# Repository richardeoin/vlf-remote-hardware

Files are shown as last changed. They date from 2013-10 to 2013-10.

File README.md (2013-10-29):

EAGLE CAD Design files for the VLF Remote Unit

## Photo

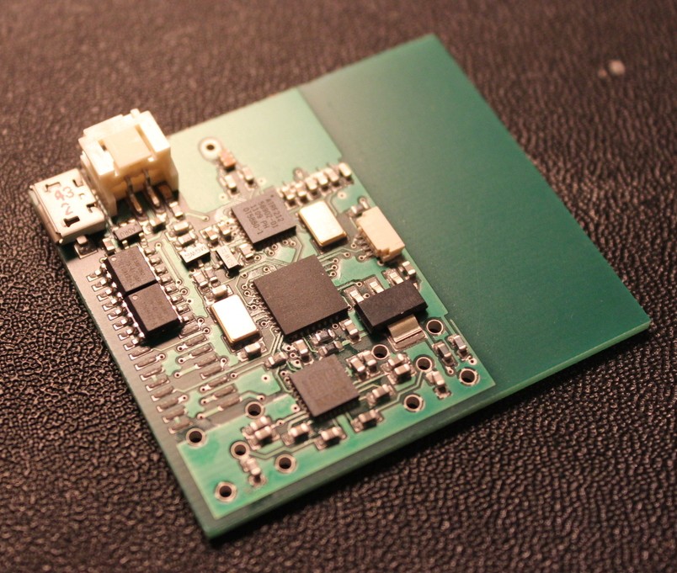
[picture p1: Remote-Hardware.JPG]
Remote Unit


## Design Notes

The board is based around a NXP
[LPC1114](http://www.nxp.com/documents/data_sheet/LPC111X.pdf) ARM
Cortex-M0 microcontroller. A Wolfson
[WM8737 ADC](http://www.wolfsonmicro.com/documents/uploads/data_sheets/en/WM8737.pdf)
is used to record the Very Low Frequency (VLF) signals. Although this
ADC is intended for audio applications it is perfectly adequate for
very low frequency RF signals due to its high gain preamplifiers. It
features low power operation and easily available, probably due to it
being
[used in the Microsoft Kinect](http://techon.nikkeibp.co.jp/english/NEWS_EN/20101205/187927/).

The board has three pads for serial flash and a
[AT86RF212](http://www.atmel.com/images/doc8168.pdf) 868MHz radio. The
range is in the order of 200m in free space, but much lower in practice.

The average current draw is approximately 3mA.

## [License](LICENSE.md)

[MIT](http://opensource.org/licenses/MIT)

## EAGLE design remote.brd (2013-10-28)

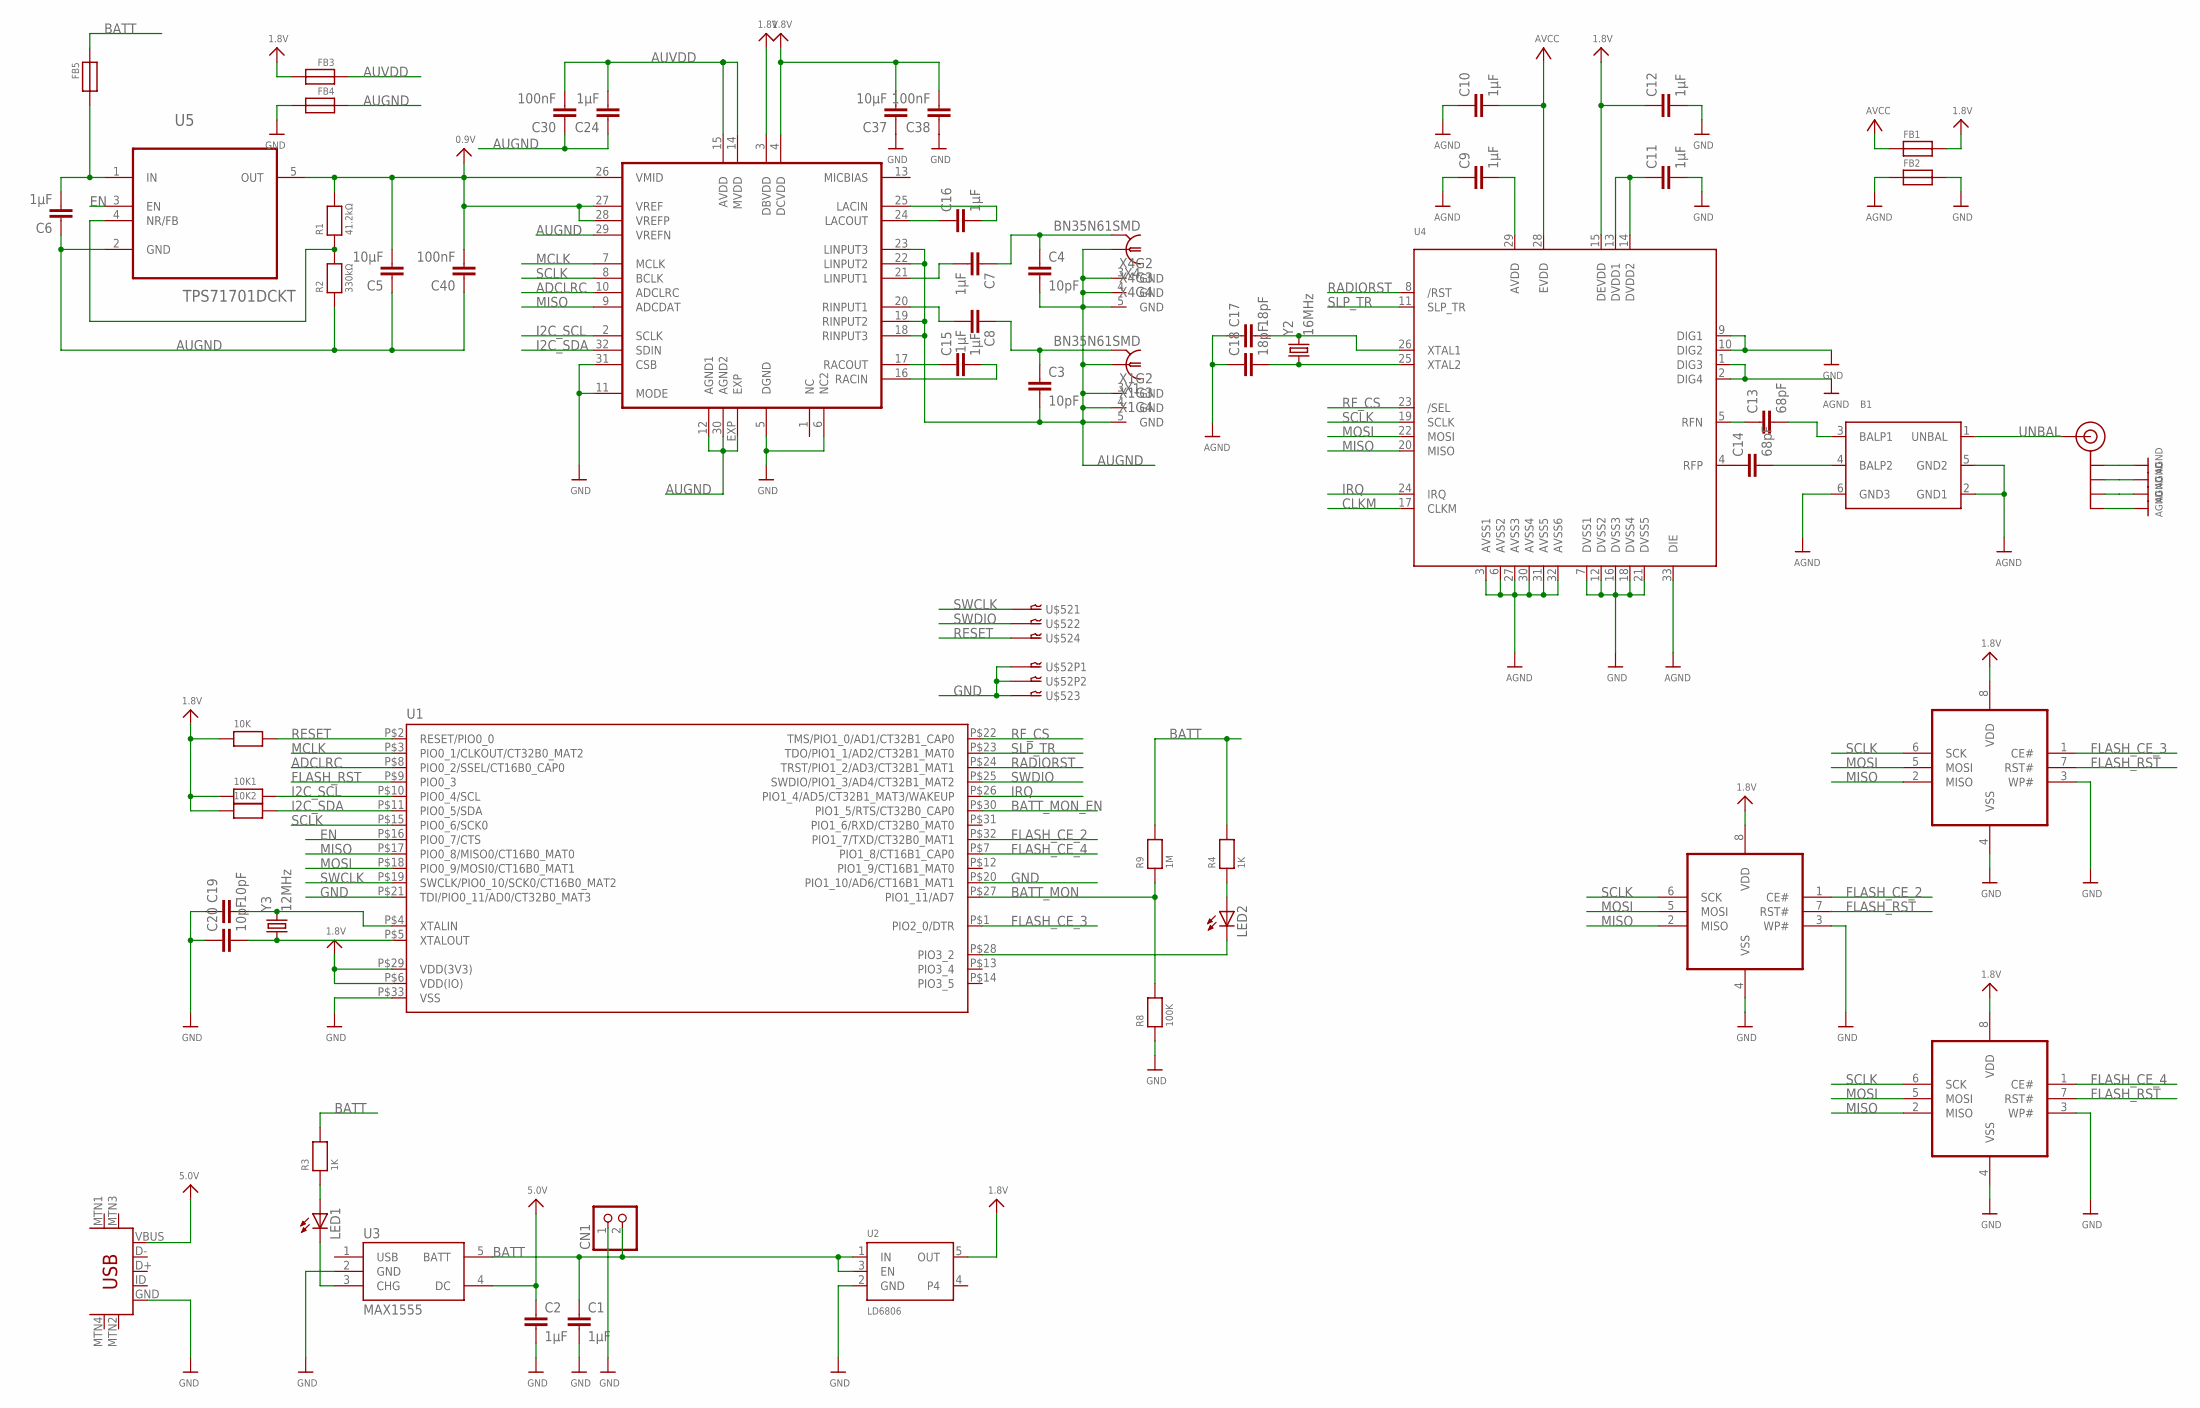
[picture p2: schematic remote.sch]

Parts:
10K, 10K1, 10K2: RESISTOR0603MINI; 0603-MINI
B1: BALUN+LP; BALUN0805
C1, C2, C6, C7, C8, C9, C10, C11, C12, C15, C16, C24: 1µF; C0603K
C3, C4, C19, C20: 10pF; C0603K
C5, C37: 10µF; C0603K
C13, C14: 68pF; C0603K
C17, C18: 18pF; C0603K
C30, C38, C40: 100nF; C0603K
CN1: JST_2PIN; JSTPH2
FB1, FB2, FB3, FB4, FB5: FERRITE; 0603
J$1: SMA_EDGE; SMA-EDGE
LED1, LED2: LEDCHIPLED_0603; CHIPLED_0603
R1: 41.2kΩ; 0603-MINI
R2: 330kΩ; 0603-MINI
R3, R4: 1K; 0603-MINI
R8: 100K; 0603-MINI
R9: 1M; 0603-MINI
U1: LPC1113/4_QFN; HVQFN33-7X7
U2: LD6806; SOT23-5
U3: MAX1555; SOT23-5
U4: AT86RF212; 32QN2
U5: TPS71701DCKT; SOT65P210X110-5N
U$1, U$22, U$26: SST25WF; ZA
U$14: WM8737; DM030FL
U$16: USB-MINIB-5PIN; USB-MINIB
U$52: SM04B-SURS-TF
X1, X4: BN35N61SMD; B35N61_SMD
Y2: 16MHz; CRYSTAL-SMD-5X3
Y3: 12MHz; CRYSTAL-SMD-5X3

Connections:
0.9V: C5.2, C40.2, R1.2, U5.5 (OUT), U$14.26 (VMID), U$14.27 (VREF), U$14.28 (VREFP)
1.8V: 10K.1, 10K1.1, 10K2.1, C12.1, C37.2, C38.2, FB1.2, FB3.2, U1.P$6 (VDD(IO)), U1.P$29 (VDD(3V3)), U2.5 (OUT), U4.15 (DEVDD), U$1.8 (VDD), U$14.3 (DBVDD), U$14.4 (DCVDD), U$22.8 (VDD), U$26.8 (VDD)
5.0V: C2.1, U3.4 (DC), U$16.VBUS
ADCLRC: U1.P$8 (PIO0_2/SSEL/CT16B0_CAP0), U$14.10 (ADCLRC)
AGND: B1.2 (GND1), B1.5 (GND2), B1.6 (GND3), C9.1, C10.1, C17.1, C18.1, FB2.1, J$1.GND@0 (GND), J$1.GND@1 (GND), J$1.GND@2 (GND), J$1.GND@3 (GND), U4.1 (DIG3), U4.2 (DIG4), U4.3 (AVSS1), U4.6 (AVSS2), U4.27 (AVSS3), U4.30 (AVSS4), U4.31 (AVSS5), U4.32 (AVSS6), U4.33 (DIE)
AUBATT: C6.2, FB5.2, U5.1 (IN)
AUGND: C3.2, C4.2, C5.1, C6.1, C24.1, C30.1, C40.1, FB4.1, R2.1, U5.2 (GND), U$14.12 (AGND1), U$14.18 (RINPUT3), U$14.19 (RINPUT2), U$14.22 (LINPUT2), U$14.23 (LINPUT3), U$14.29 (VREFN), U$14.30 (AGND2), U$14.EXP, X1.2 (1), X1.3 (GND), X1.4 (GND), X1.5 (GND), X4.2 (1), X4.3 (GND), X4.4 (GND), X4.5 (GND)
AUVDD: C24.2, C30.2, FB3.1, U$14.14 (MVDD), U$14.15 (AVDD)
AVCC: C10.2, FB1.1, U4.28 (EVDD)
AVDD-IN: C9.2, U4.29 (AVDD)
BALP1: B1.3 (BALP1), C13.2
BALP2: B1.4 (BALP2), C14.2
BATT: C1.1, CN1.2, FB5.1, R3.2, R4.2, R9.2, U2.1 (IN), U2.3 (EN), U3.5 (BATT)
BATT_MON: R8.2, R9.1, U1.P$27 (PIO1_11/AD7)
BATT_MON_EN: U1.P$30 (PIO1_5/RTS/CT32B0_CAP0)
CHG: LED1.C, U3.3 (CHG)
CHG_LED: LED1.A, R3.1
CHG_LED1: LED2.A, R4.1
CLKM: U4.17 (CLKM)
EN: U1.P$16 (PIO0_7/CTS), U5.3 (EN)
FLASH_CE_2: U1.P$32 (PIO1_7/TXD/CT32B0_MAT1), U$26.1 (CE#)
FLASH_CE_3: U1.P$1 (PIO2_0/DTR), U$22.1 (CE#)
FLASH_CE_4: U1.P$7 (PIO1_8/CT16B1_CAP0), U$1.1 (CE#)
FLASH_RST: U1.P$9 (PIO0_3), U$1.7 (RST#), U$22.7 (RST#), U$26.7 (RST#)
GND: C1.2, C2.2, C11.2, C12.2, C19.1, C20.1, C37.1, C38.1, CN1.1, FB2.2, FB4.2, R8.1, U1.P$20 (PIO1_10/AD6/CT16B1_MAT1), U1.P$21 (TDI/PIO0_11/AD0/CT32B0_MAT3), U1.P$33 (VSS), U2.2 (GND), U3.2 (GND), U4.7 (DVSS1), U4.9 (DIG1), U4.10 (DIG2), U4.12 (DVSS2), U4.16 (DVSS3), U4.18 (DVSS4), U4.21 (DVSS5), U$1.3 (WP#), U$1.4 (VSS), U$14.5 (DGND), U$14.6 (NC2), U$14.11 (MODE), U$14.31 (CSB), U$16.GND, U$22.3 (WP#), U$22.4 (VSS), U$26.3 (WP#), U$26.4 (VSS), U$52.3, U$52.GND1, U$52.GND2
I2C_SCL: 10K1.2, U1.P$10 (PIO0_4/SCL), U$14.2 (SCLK)
I2C_SDA: 10K2.2, U1.P$11 (PIO0_5/SDA), U$14.32 (SDIN)
IRQ: U1.P$26 (PIO1_4/AD5/CT32B1_MAT3/WAKEUP), U4.24 (IRQ)
LPC_XTAL1: C19.2, U1.P$4 (XTALIN), Y3.3 (2)
LPC_XTAL2: C20.2, U1.P$5 (XTALOUT), Y3.1
MCLK: U1.P$3 (PIO0_1/CLKOUT/CT32B0_MAT2), U$14.7 (MCLK)
MISO: U1.P$17 (PIO0_8/MISO0/CT16B0_MAT0), U4.20 (MISO), U$1.2 (MISO), U$14.9 (ADCDAT), U$22.2 (MISO), U$26.2 (MISO)
MOSI: U1.P$18 (PIO0_9/MOSI0/CT16B0_MAT1), U4.22 (MOSI), U$1.5 (MOSI), U$22.5 (MOSI), U$26.5 (MOSI)
unnamed: LED2.C, U1.P$28 (PIO3_2)
unnamed: C8.2, U$14.20 (RINPUT1)
unnamed: C3.1, C8.1, X1.1 (GND)
unnamed: C4.1, C7.1, X4.1 (GND)
unnamed: C11.1, U4.13 (DVDD1), U4.14 (DVDD2)
unnamed: C7.2, U$14.21 (LINPUT1)
unnamed: C16.1, U$14.24 (LACOUT)
unnamed: C15.1, U$14.17 (RACOUT)
unnamed: C16.2, U$14.25 (LACIN)
unnamed: C15.2, U$14.16 (RACIN)
unnamed: R1.1, R2.2, U5.4 (NR/FB)
RADIORST: U1.P$24 (TRST/PIO1_2/AD3/CT32B1_MAT1), U4.8 (/RST)
RESET: 10K.2, U1.P$2 (RESET/PIO0_0), U$52.4
RFN: C13.1, U4.5 (RFN)
RFP: C14.1, U4.4 (RFP)
RF_CS: U1.P$22 (TMS/PIO1_0/AD1/CT32B1_CAP0), U4.23 (/SEL)
RF_XTAL1: C17.2, U4.26 (XTAL1), Y2.3 (2)
RF_XTAL2: C18.2, U4.25 (XTAL2), Y2.1
SCLK: U1.P$15 (PIO0_6/SCK0), U4.19 (SCLK), U$1.6 (SCK), U$14.8 (BCLK), U$22.6 (SCK), U$26.6 (SCK)
SLP_TR: U1.P$23 (TDO/PIO1_1/AD2/CT32B1_MAT0), U4.11 (SLP_TR)
SWCLK: U1.P$19 (SWCLK/PIO0_10/SCK0/CT16B0_MAT2), U$52.1
SWDIO: U1.P$25 (SWDIO/PIO1_3/AD4/CT32B1_MAT2), U$52.2
UNBAL: B1.1 (UNBAL), J$1.SIG (SIGNAL)

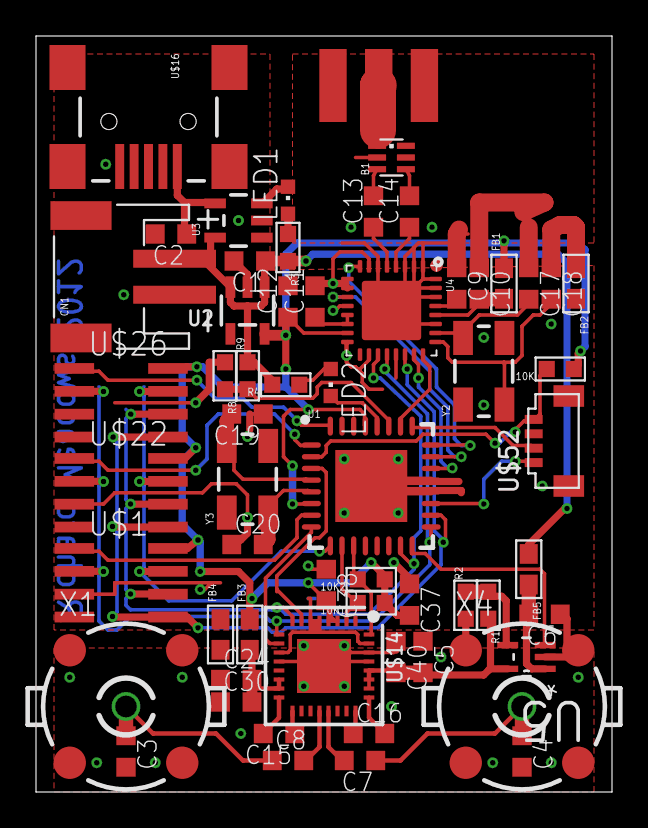
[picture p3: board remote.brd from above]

Board: 2 copper layers, 32.0 x 42.0 mm, 59 parts (0 on the bottom side), 54 nets.

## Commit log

2013-10-28 Version 1
    [VLFAudioLogger.brd, VLFAudioLogger.sch]
2013-10-28 Version 2
    [VLFAudioLogger.brd, VLFAudioLogger.sch]
2013-10-28 Version 3
    [VLFAudioLogger.brd, VLFAudioLogger.sch]
2013-10-28 Version 4
    [VLFAudioLogger.brd, VLFAudioLogger.sch]
2013-10-28 Added photo, renamed EAGLE Design Files
    [remote.brd, remote.sch]

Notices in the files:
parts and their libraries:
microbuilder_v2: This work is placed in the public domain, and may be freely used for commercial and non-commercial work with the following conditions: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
